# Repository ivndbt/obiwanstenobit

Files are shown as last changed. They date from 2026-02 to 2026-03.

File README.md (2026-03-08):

# ObiWanStenobit

Open-source steno keyboard with a pseudo-split layout, designed to be compact, portable, and cost-effective.

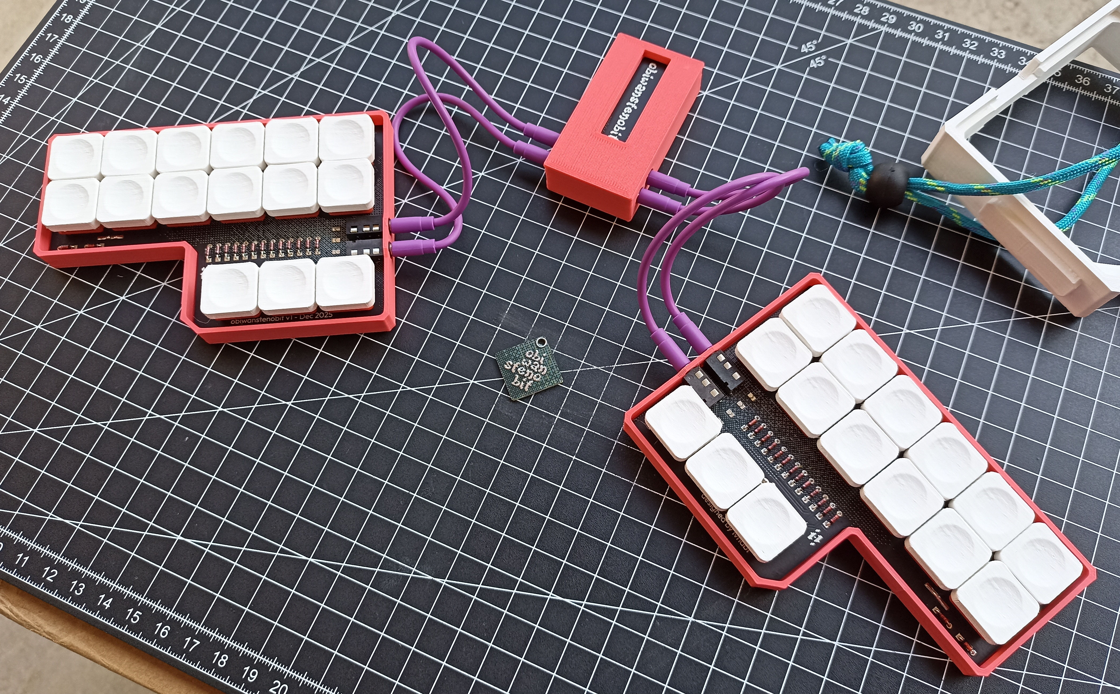
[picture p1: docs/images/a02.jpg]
ObiWanStenobit


## Overview

ObiWanStenobit (OWS) is a 30-key, steno-oriented mechanical keyboard designed with the primary goals of low manufacturing cost and ease of transport.

The keyboard uses a pseudo-split architecture: it is physically split into two halves, but relies on a single microcontroller rather than the dual-controller setup typical of traditional split keyboards.

The PCB is panelized and kept under 100x100mm to reduce fabrication costs and allow the keyboard to be built from a single PCB order (minimum 2 units).

The provided 3D-printable case is designed to be easily closed and to protect switches and electronic components during transport, making the keyboard suitable for backpack travel.

More information about the design process and development history are available at [ivndbt.com](https://ivndbt.com/makes/ows/ows.html)

## Features

- Pseudo-split steno layout
- Single microcontroller design
- Panelized PCB (< 100x100mm)
- Pro Micro compatible controller
- Kailh Choc v1 and v2 switch support
- Compact and travel-friendly form factor
- Open hardware design

## Repository structure

- `/`
  - Build guide (including BOM)
- `hardware/pcb/`
  - KiCad project files
  - Manufacturing-ready Gerber files
- `hardware/case/`
  - FreeCAD source files
  - STL files for 3D printing
- `docs/`
  - Images and additional files

## Hardware

### PCB

The PCB is designed in KiCad and provided both as source files and pre-generated Gerber files.  
Panelization is included in the design to minimize fabrication costs.

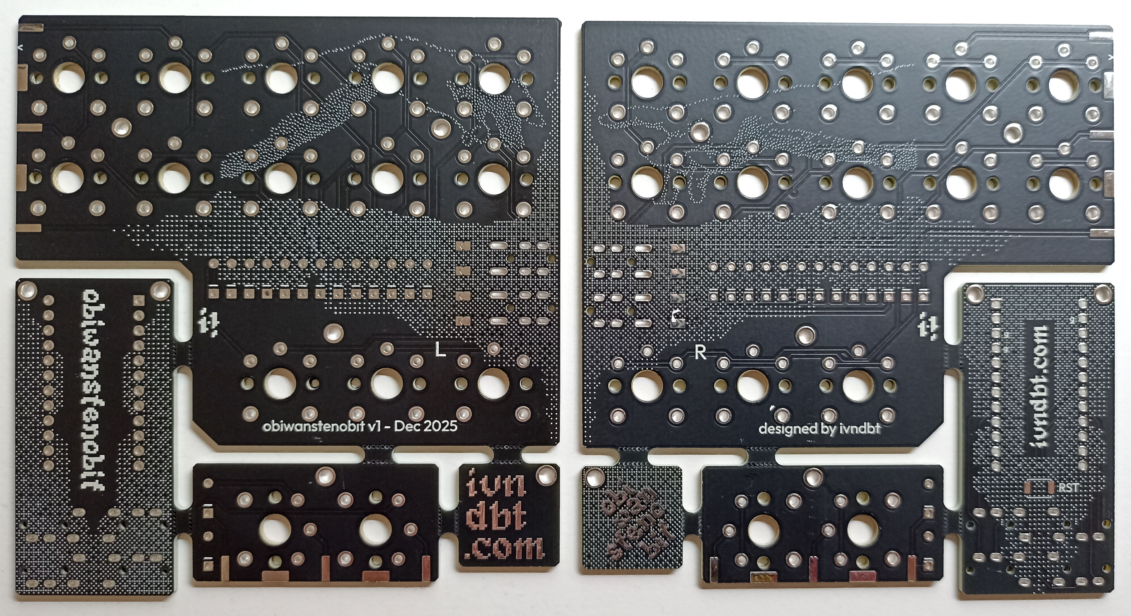
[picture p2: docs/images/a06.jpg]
PCB


### Case

The case is designed in FreeCAD.  
STL files provided in this repository should be considered the authoritative and up-to-date versions.
STLs hosted on [Printables]() are provided for convenience, but are not guaranteed to be updated to the latest revision.  

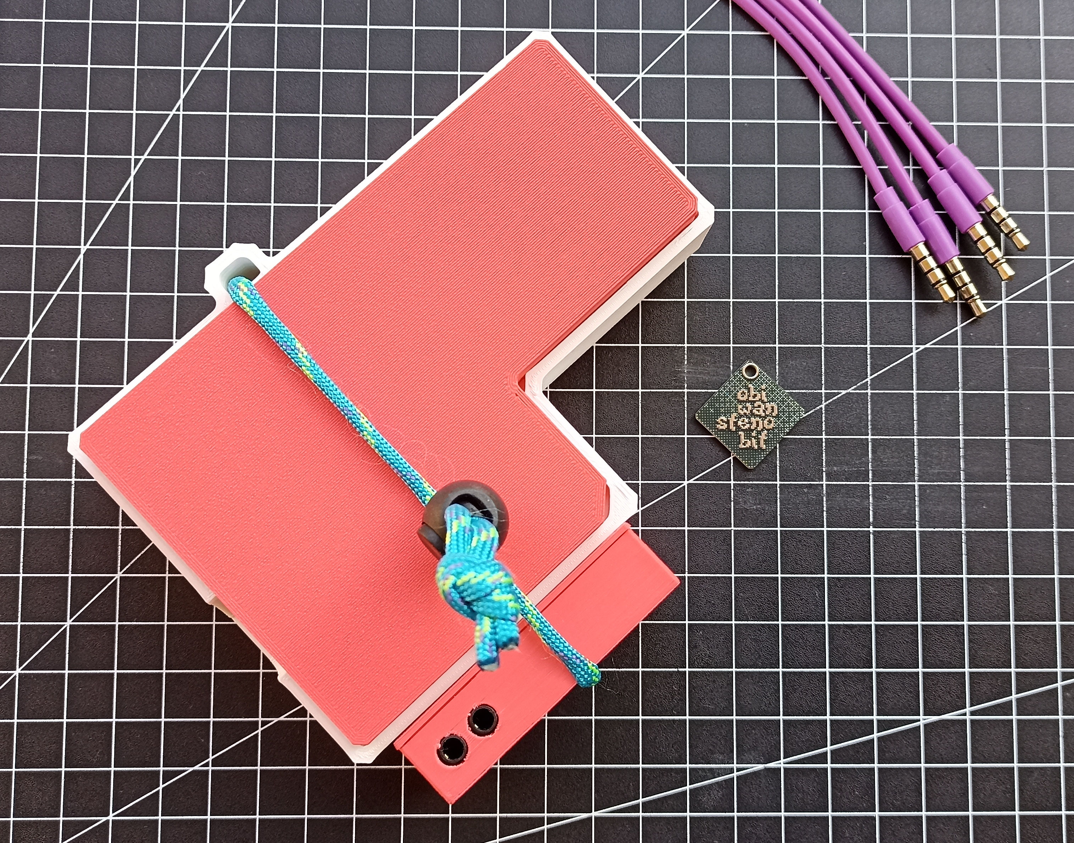
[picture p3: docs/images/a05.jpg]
Case


## Firmware

ObiWanStenobit can run on different firmware:

- QMK: [qmk/qmk_firmware](https://github.com/qmk/qmk_firmware/tree/master/keyboards/ivndbt/ows)
- ZMK: [ivndbt/zmk-config-obiwanstenobit](https://github.com/ivndbt/zmk-config-obiwanstenobit)
- Javelin: [ivndbt/javelin-steno-pico/artifacts_ows](https://github.com/ivndbt/javelin-steno-pico/tree/add-ows/artifacts_ows)
- VIA: [ivndbt/qmk_userspace](https://github.com/ivndbt/qmk_userspace/tree/add-ows-via) pending PR
- Vial: [vial-kb/vial-qmk](https://github.com/vial-kb/vial-qmk/tree/vial/keyboards/ivndbt/ows)

Firmware is maintained in the respective upstream repositories.

## Build guide

Assembly instructions and the complete Bill of Materials are provided in `build-guide.md`

## Extra files

`docs/` directory contains supplementary files related to the ObiWanStenobit keyboard development.

- `KLE-ows-via.json`: mapping matrix coordinates for [Keyboard Layout Editor](https://www.keyboard-layout-editor.com/).

## License

This project is licensed under **CERN Open Hardware Licence v2 (CERN-OHL-S)**.

You are free to use, modify, manufacture, and distribute this project under the terms of the license.
Any redistribution should include proper attribution and a reference to the original source:

    Based on ObiWanStenobit by ivndbt, licensed under CERN-OHL-S v2.
    Source: https://github.com/ivndbt/obiwanstenobit

See the `LICENSE` file for details.

If you are interested in producing this design, creating variants, or collaborating, you are welcome to get in touch via the email address found at [ivndbt.com](https://ivndbt.com/#contact).

## Sponsors

PCB prototyping was sponsored by [PCBWay](https://www.pcbway.com/), who kindly manufactured and provided the prototype boards.\
Fabrication quality and turnaround time were solid. Read more about it in [my blogpost](https://ivndbt.com/makes/ows/ows.html).

## References

- The ObiWanStenobit layout is inspired by [The Uni](https://stenokeyboards.com/products/the-uni-v4) from [StenoKeyboards](https://stenokeyboards.com/)
- The logo uses the [Kiwi Soda](https://fontenddev.com/fonts/kiwi-soda/) font from [fontenddev.com](https://fontenddev.com/)

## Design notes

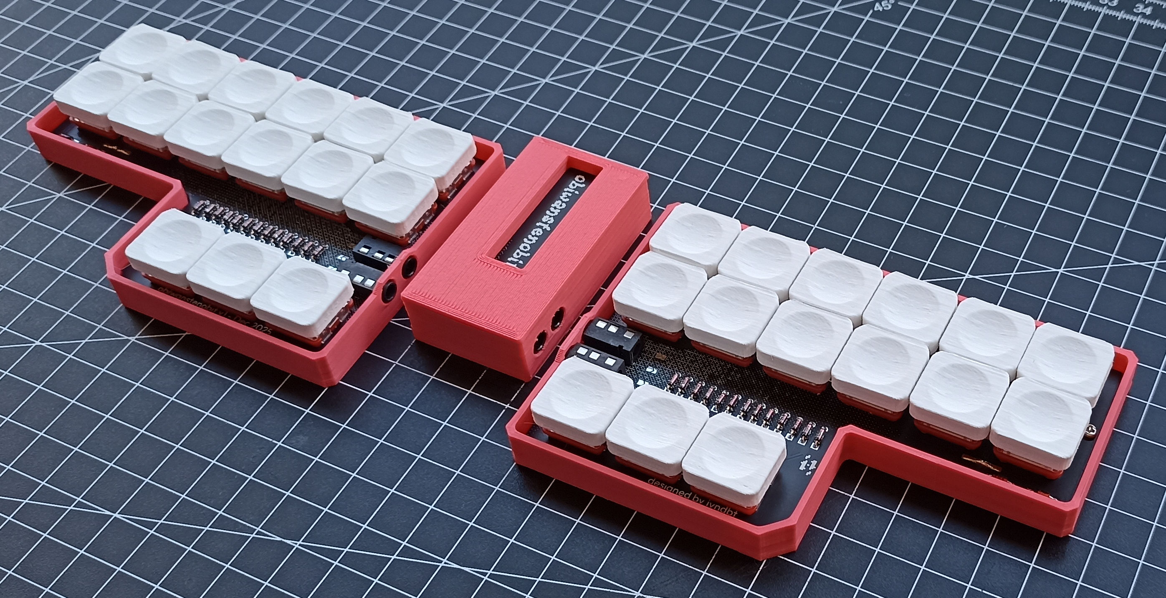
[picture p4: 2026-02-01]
docs/images/a01.jpg

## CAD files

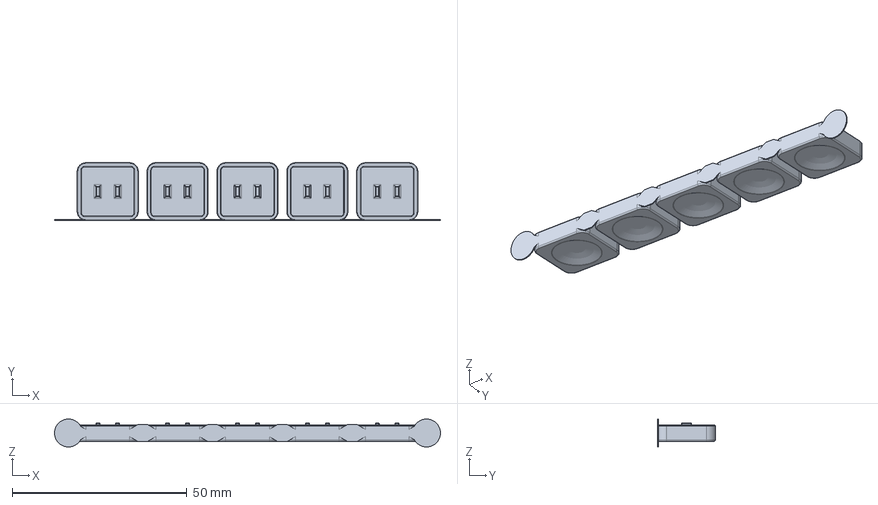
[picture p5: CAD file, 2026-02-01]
hardware/case/freecad/1c_choc_x5.FCStd
110.5 x 16.5 x 8.00 mm

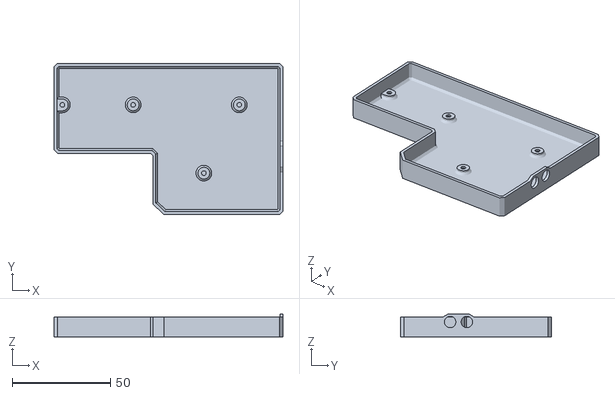
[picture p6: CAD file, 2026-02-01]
hardware/case/stl/kb-l.stl
116.5 x 77.0 x 11.6

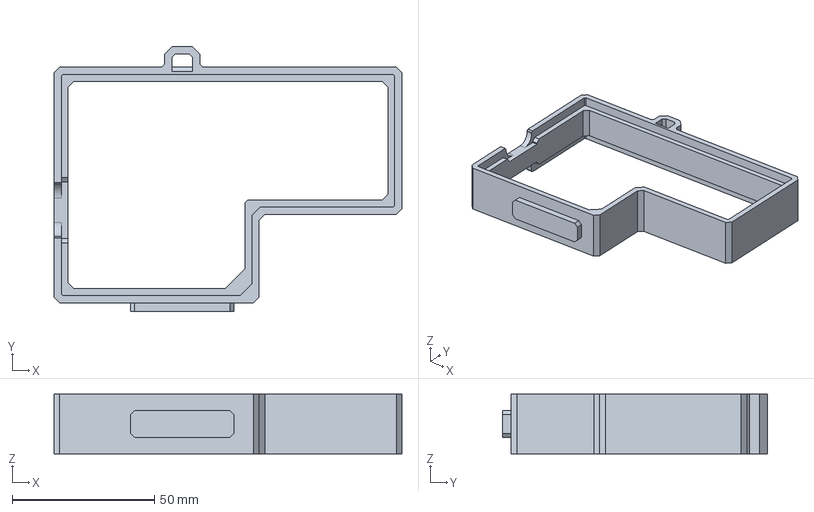
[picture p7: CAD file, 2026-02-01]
hardware/case/freecad/holder-v2.FCStd
122.5 x 93.2 x 21.0 mm

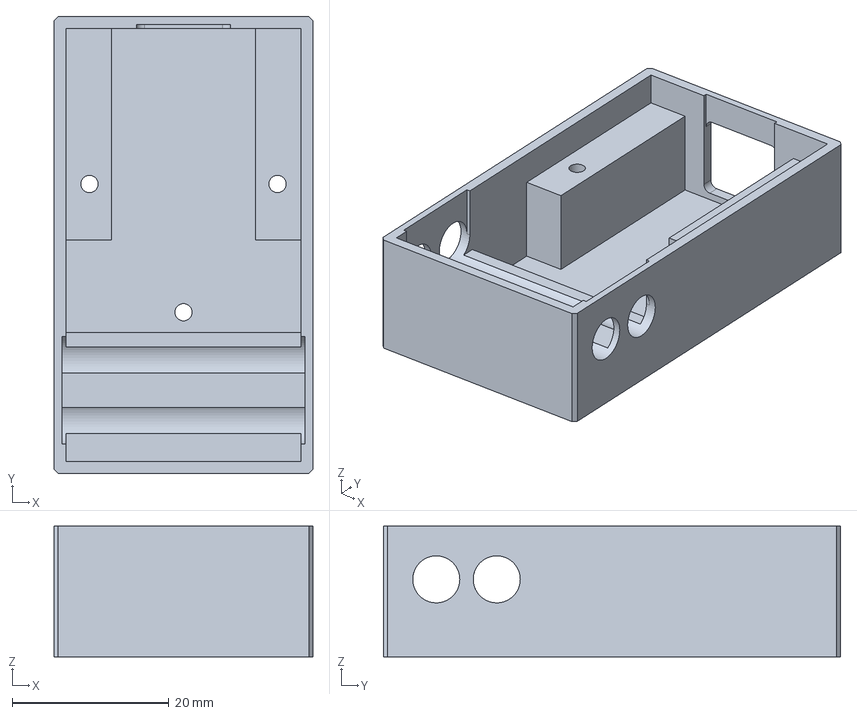
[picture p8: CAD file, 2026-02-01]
hardware/case/freecad/bay-bot-1.1.FCStd
33.0 x 58.3 x 16.7 mm

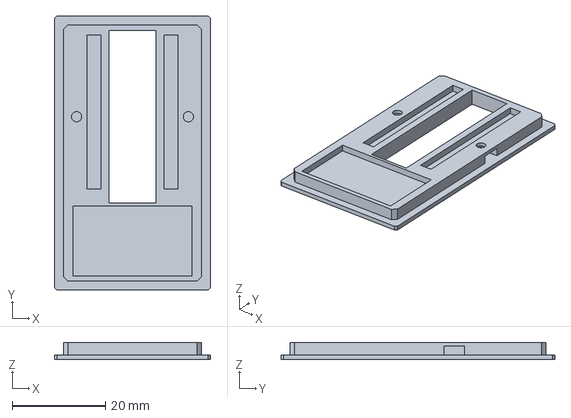
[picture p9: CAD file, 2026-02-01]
hardware/case/freecad/bay-top-1.1.FCStd
33.5 x 58.8 x 3.70 mm

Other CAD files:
hardware/case/freecad/kb-r.FCStd
hardware/case/stl/bay-bot-1.1.stl
hardware/case/stl/bay-top-1.1.stl
hardware/case/stl/holder-v2.stl
hardware/case/stl/kb-r.stl

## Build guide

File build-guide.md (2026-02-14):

# ObiWanStenobit – Build Guide

This document describes the complete build process for the **ObiWanStenobit (OWS)** keyboard, from PCB preparation to firmware flashing and initial steno setup.

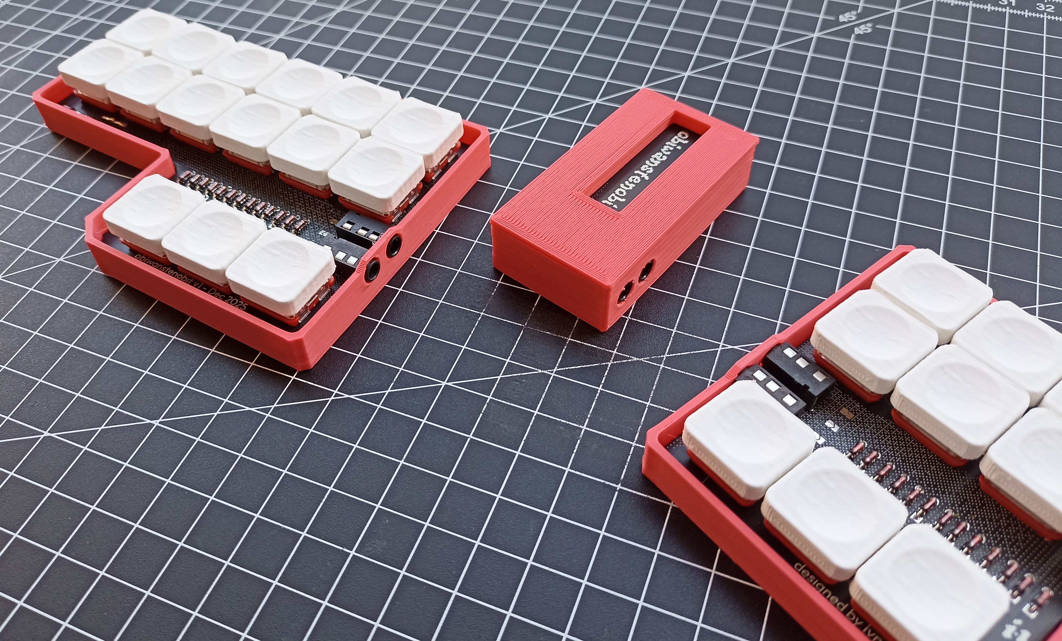
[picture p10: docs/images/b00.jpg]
Final result


## Bill of Materials

The following table lists all required and optional components needed to build a complete ObiWanStenobit keyboard compatible with the provided case.

| Ref. | Component | Description | Quantity | Links |
|---|---|---|---|---|
| 1 | PCBs | OWS panelized full set | 2 | [Gerbers](/hardware/pcb/gerber) |
| 2 | RP2040 | Pro Micro edition 16M | 1 | [Aliexpress](https://it.aliexpress.com/item/1005009348943760.html) |
| 3 | Socket | M2F 12-pin[^1] | 2 | [Aliexpress](https://it.aliexpress.com/item/1005007476809536.html) |
| 4 | Pins | MCU header pins[^1] | 24 | [Aliexpress](https://it.aliexpress.com/item/1005010342280815.html) |
| 5 | Kailh switches | Choc V1 (or V2) | 30 | [Aliexpress](https://it.aliexpress.com/item/1005008883418065.html) |
| 6 | PJ-320A | THT TRRS jack socket[^2] | 8 | [Aliexpress](https://it.aliexpress.com/item/1005007334594658.html) |
| 7 | Tactile switch | SMD 2-pin 4x3x2mm | 1 | [Aliexpress](https://it.aliexpress.com/item/1005010586092874.html) |
| 8 | Diode | DO-35 1N4148 | 30 | [Aliexpress](https://it.aliexpress.com/item/32947233235.html) |
| 9 | TRRS cables | Male-to-male TRRS cable[^2] | 4 | [Aliexpress](https://it.aliexpress.com/item/32462922130.html) |
| 10 | Pins | M2M header pin | 6 | [Aliexpress](https://it.aliexpress.com/item/4000988113226.html) |
| 11 | Keycaps | Compatibles with Choc V1 | 30 | [STL](/hardware/case/stl) / [Aliexpress](https://it.aliexpress.com/item/1005009100305250.html) |
| 12 | Case | | 1 | [STL](/hardware/case/stl) |
| 13 | Screws | M2x4mm cylindrical head PH  | 8 | [Aliexpress](https://it.aliexpress.com/item/32971605141.html) |
| 14 | Screws | M2x10mm cylindrical head PH | 2 | [Aliexpress](https://it.aliexpress.com/item/32971605141.html) |
| 15 | Nuts | M2 hex | 10 | [Aliexpress](https://it.aliexpress.com/item/1005007796257329.html) |
| opt. | Rubber feet | | 8 | [Aliexpress](https://it.aliexpress.com/item/1005002619943801.html) |
| opt. | Nut | 1/4in-20 | 1 | |
| opt. | Paracord | 550 | 50cm | [Aliexpress](https://it.aliexpress.com/item/4000176073490.html) |
| opt. | Spring buckle | | 1 | [Aliexpress](https://it.aliexpress.com/item/1005003036732343.html) |

[^1]: To socket the MCU as low as possible, the use of Mill-Max pin headers is recommended.

[^2]: TRRS connectors (4 rings) are required.

## Required and Recommended Tools

### Required tools

- Soldering iron
- Solder wire
- Flush cutters
- Pliers
- Tweezers
- Fine-grit sandpaper

### Recommended tools

- Flux

## Terminology and PCB Nomenclature

The following terminology is used throughout this guide:

- **Main Keyboard PCB**: the primary PCB hosting the majority of switches (left and right)
- **2-Key Expansion PCB**: the auxiliary PCB hosting the additional two keys
- **Controller PCB**: the PCB hosting the microcontroller and connectors

## PCB Preparation

Separate all PCBs by breaking the mouse bites from two full PCB sets.  
One extra Controller PCB will remain unused.

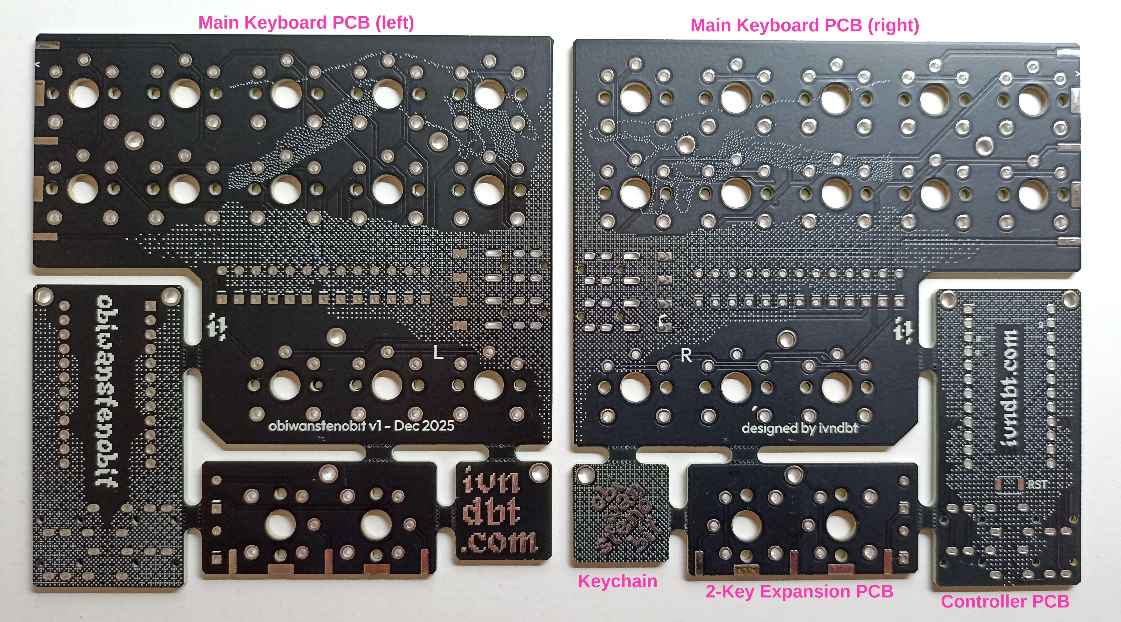
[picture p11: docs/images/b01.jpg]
2 full sets of PCBs


Place a sheet of fine-grit sandpaper on a flat surface and gently sand the PCB edges to remove mouse bite remnants.  
Edges should be smooth to the touch.

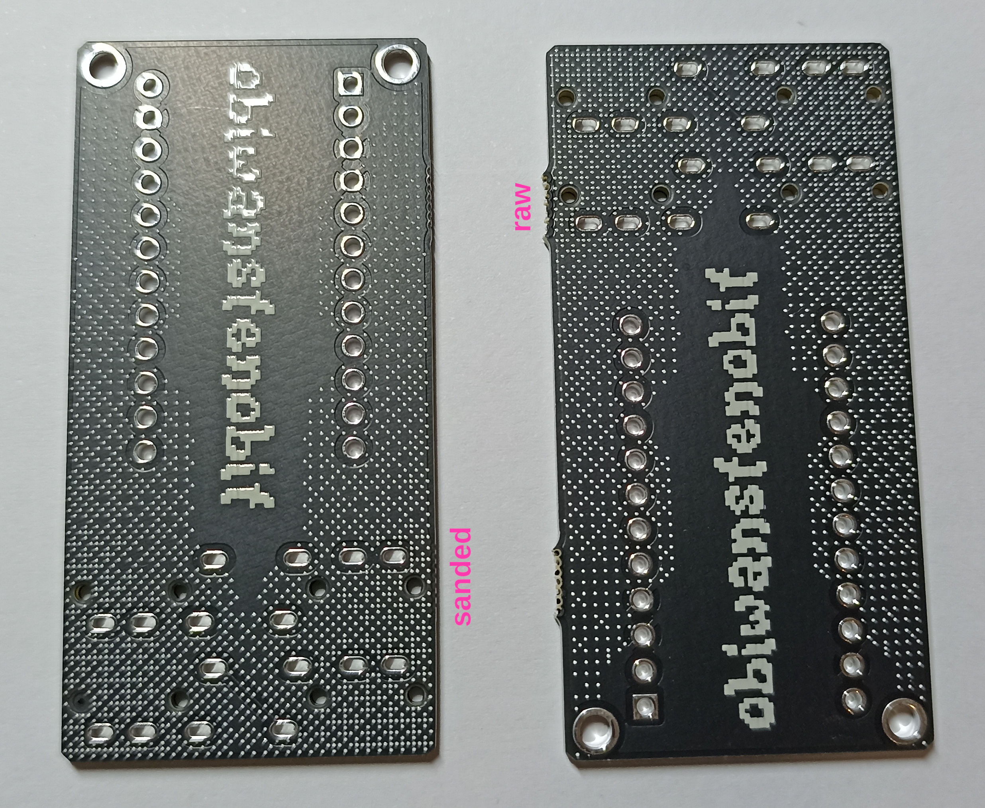
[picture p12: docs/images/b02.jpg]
Before and after edge sanding


## Controller Preparation

This section is based on the guide provided for the Aurora series by [splitkb.com](https://splitkb.com/).  
Refer to the [original documentation](https://docs.splitkb.com/product-guides/aurora-series/build-guide/microcontrollers#using-mill-max-pins) for additional images.

Using sockets allows the microcontroller to be removed or replaced if necessary.  

Before starting, identify the correct controller orientation.  
The MCU is mounted above the **ivndbt.com** logo, with the chip facing the user.

Insert the sockets into the controller PCB and solder **one pin per socket** first.  
Check alignment carefully: if needed, reheat the joint and adjust.  
Once aligned, solder the remaining outer pins.

Before inserting the header pins, place a thin **plastic barrier** over the sockets to prevent solder from flowing inside them.  
Kapton tape is recommended, but a piece of sturdy plastic is fine too.
Failing to do this step can permanently solder the controller to the sockets, making removal nearly impossible.

Insert the header pins into the sockets one by one, pushing them fully.  

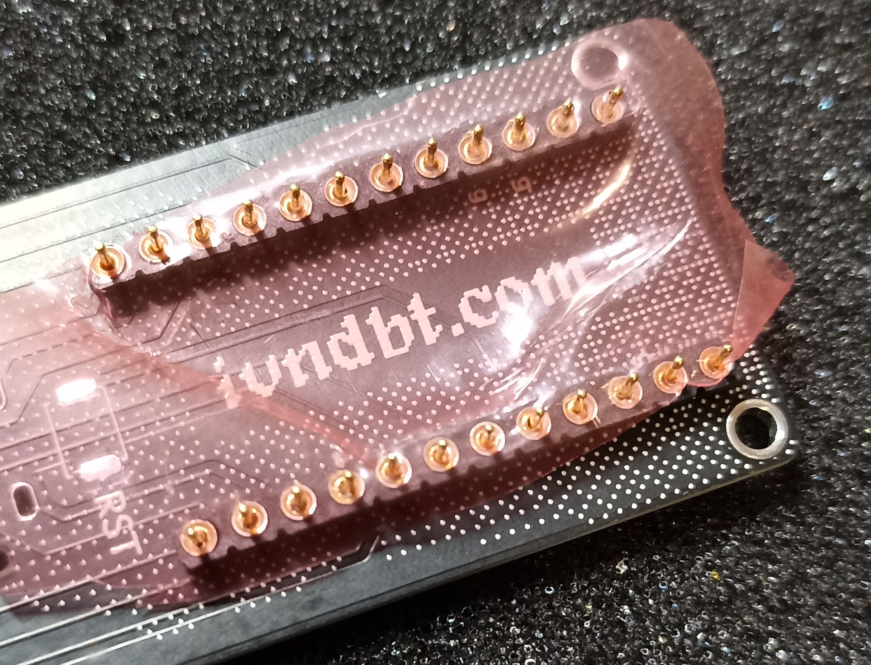
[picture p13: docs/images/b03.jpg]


Place the microcontroller onto the pins and solder it in place.

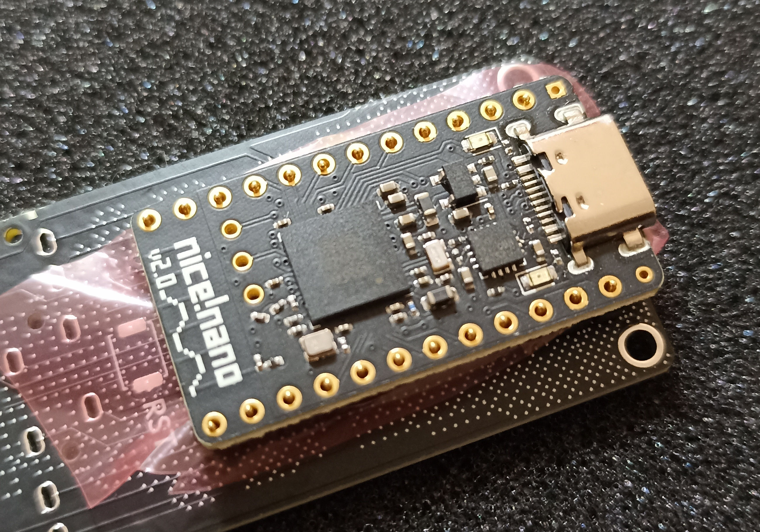
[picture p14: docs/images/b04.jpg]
nice!nano position


The image shows a nice!nano controller, but the procedure is identical for the RP2040. If your pins are too long, cut them with the flush cutter.

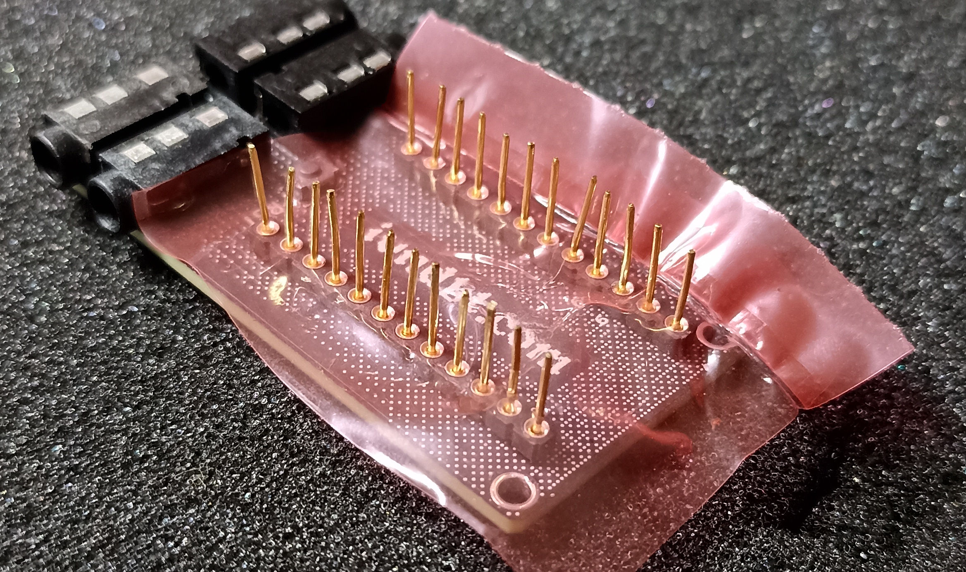
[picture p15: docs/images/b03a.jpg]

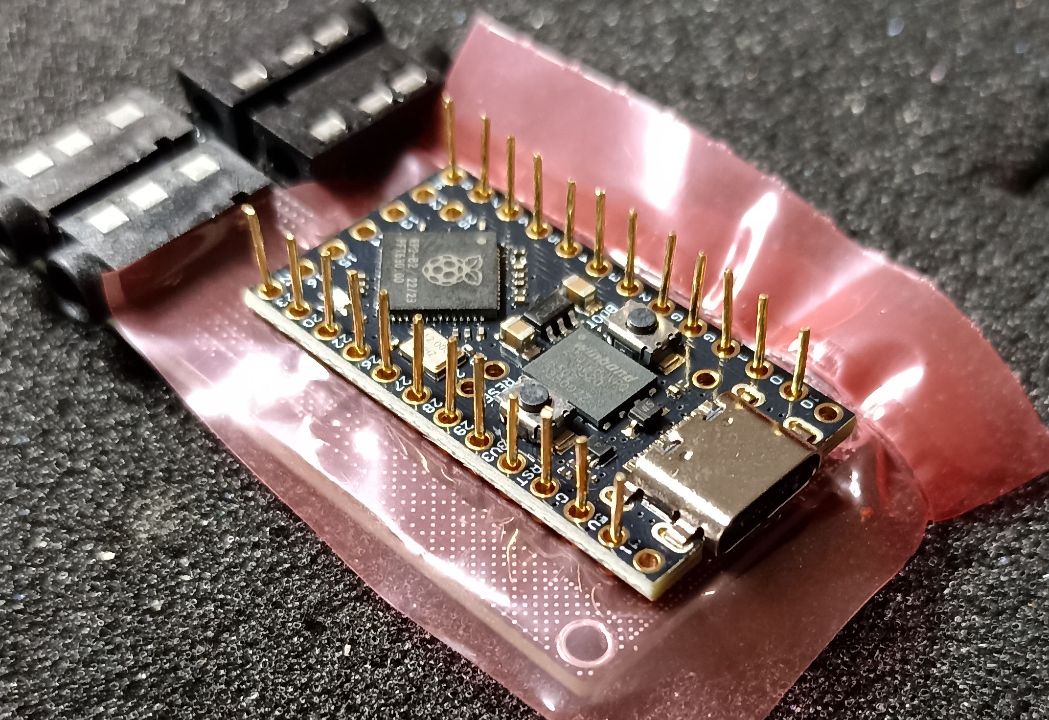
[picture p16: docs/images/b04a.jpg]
RP2040 position

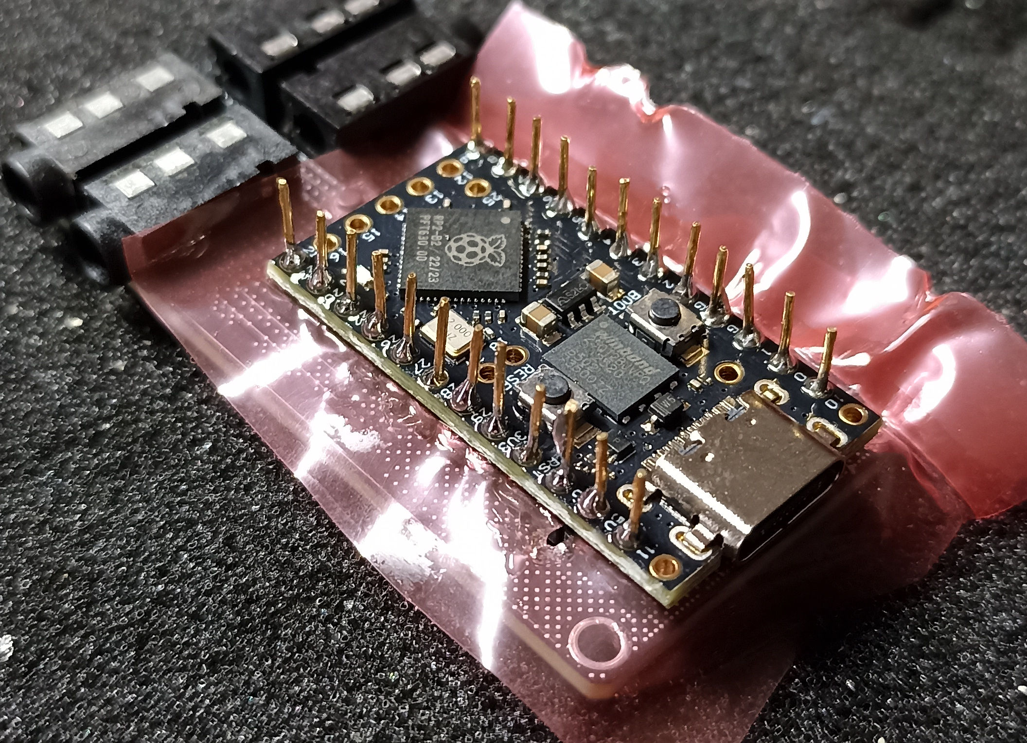
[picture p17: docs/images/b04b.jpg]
RP2040 soldered with long pins

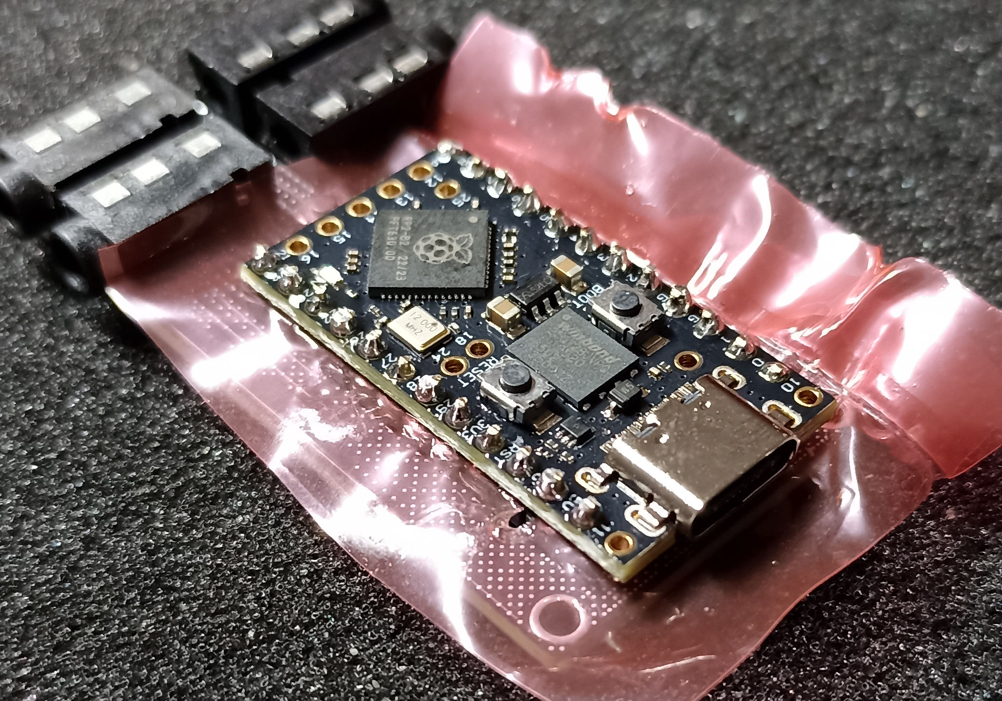
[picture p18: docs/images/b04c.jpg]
RP2040 pins cut


>The two holes near the USB connector must not be soldered in both cases.

After soldering, carefully remove the plastic layer.  
Take care not to bend the controller pins when mounting or removing the MCU.

## Controller PCB

Complete the controller PCB by soldering:

- The reset button
- The four TRRS jack sockets

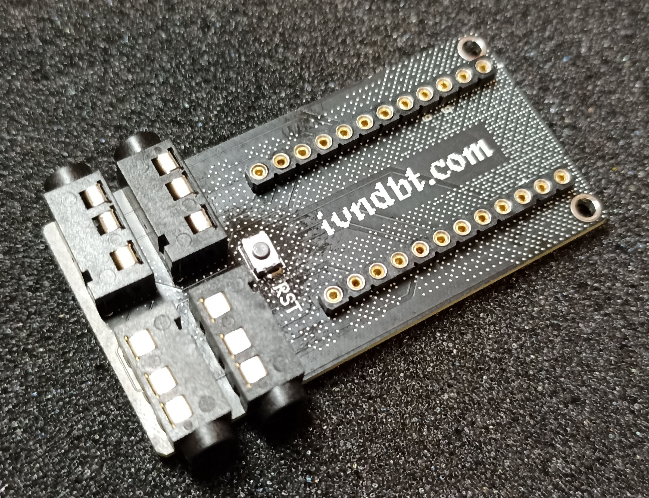
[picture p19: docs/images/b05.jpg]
Complete Controller PCB


## Main Keyboard

### Soldering the PCBs

Place the Main Keyboard PCB and the 2-Key Expansion PCB on a flat surface with the switch side facing up.  
Align the edges carefully and solder the interconnecting pads generously.

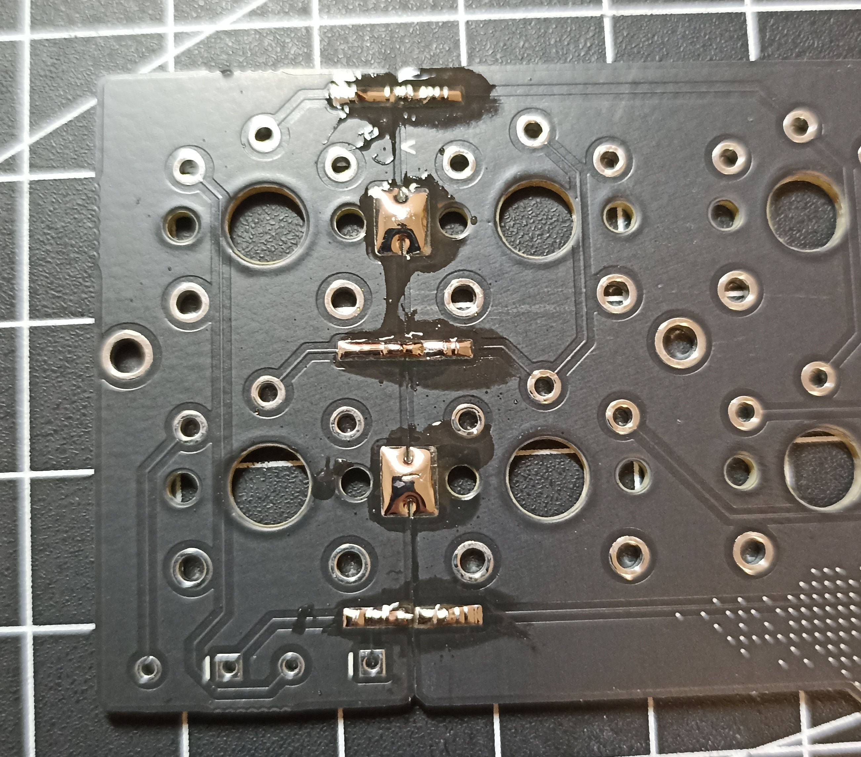
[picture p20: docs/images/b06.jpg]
Frontside connection


Flip the PCB assembly and solder the pads on the backside as well.

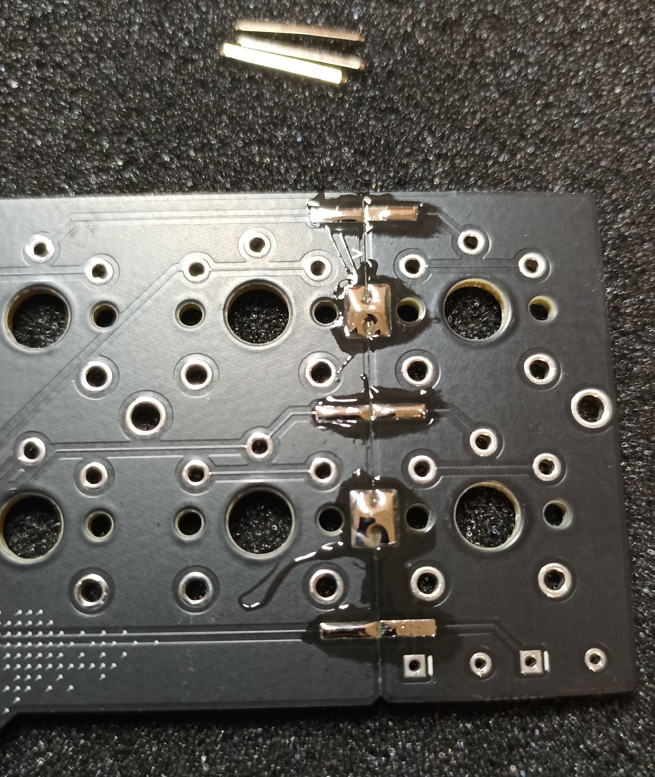
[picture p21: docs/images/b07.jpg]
Backside connection


For improved mechanical strength, it is recommended to embed a square-section header pin into each of the thin interconnection pads **on the backside**.
To do this, reheat the solder and gently place the pin into position. Add solder if necessary to secure it.

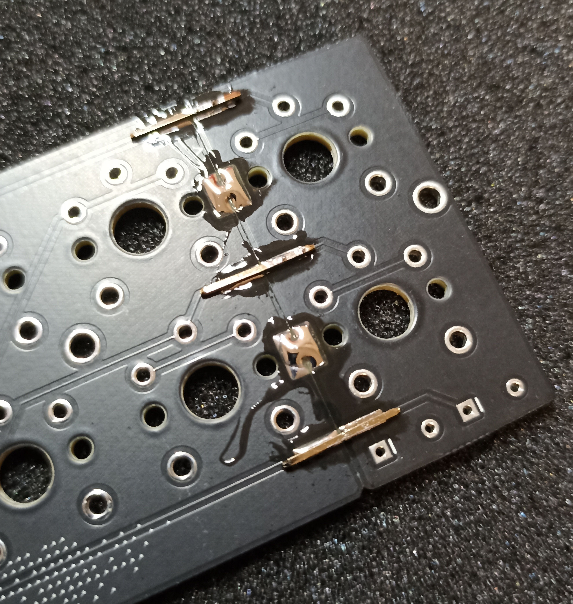
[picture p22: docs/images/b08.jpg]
Backside reinforced connection


### Diodes

Identify diode polarity.  
The line printed on the PCB marks the cathode and must align with the line on the diode.

Bend the diode leads as close as possible to the diode body before insertion.  

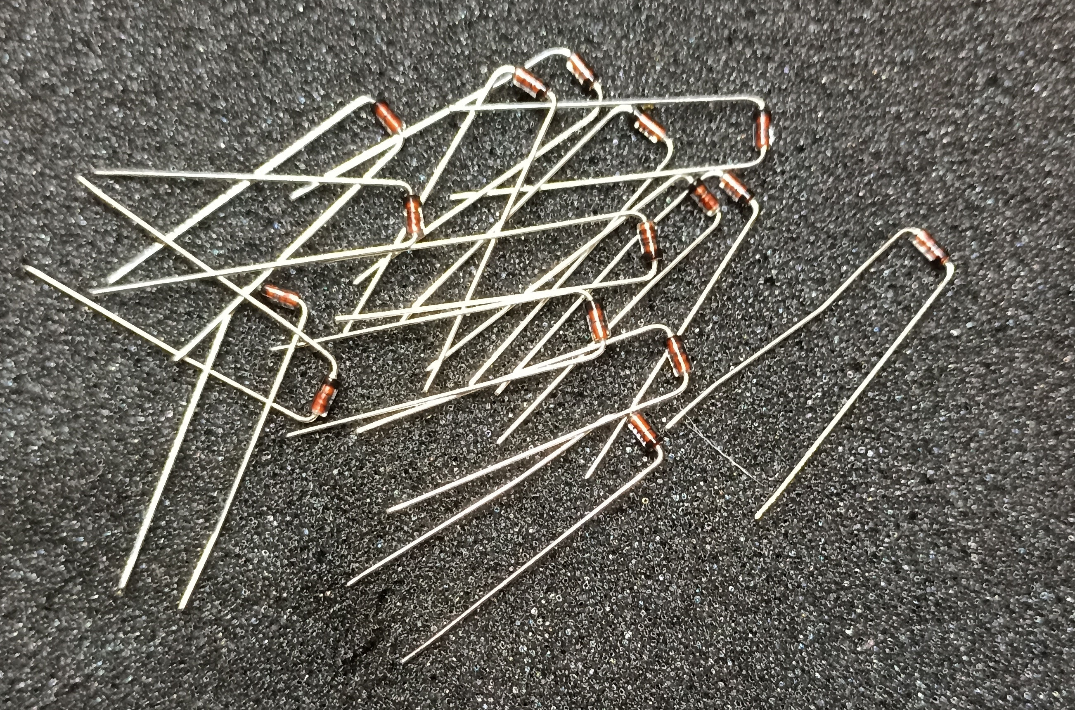
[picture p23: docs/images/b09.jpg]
Diodes preparation


Solder all diodes on the front side of the PCBs and cut the exceeding leads.

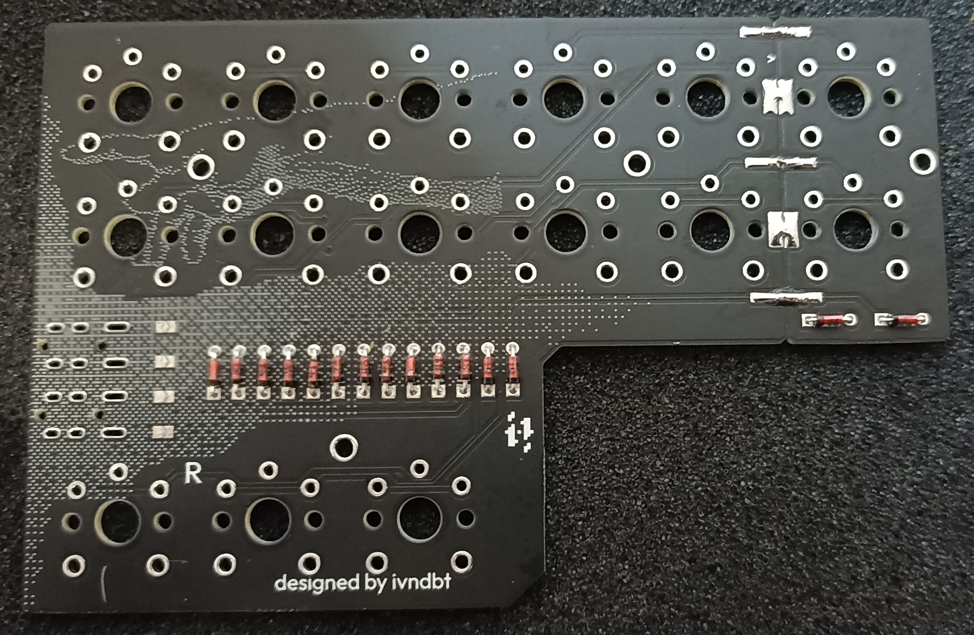
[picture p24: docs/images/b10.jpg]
Diodes soldered


### Jack Sockets and Solder Jumpers

On the front side of the PCBs, place and solder all jack sockets.

Solder **only the solder jumpers on the backside of both PCBs**.  
The solder jumpers on the front side **must not** be soldered.

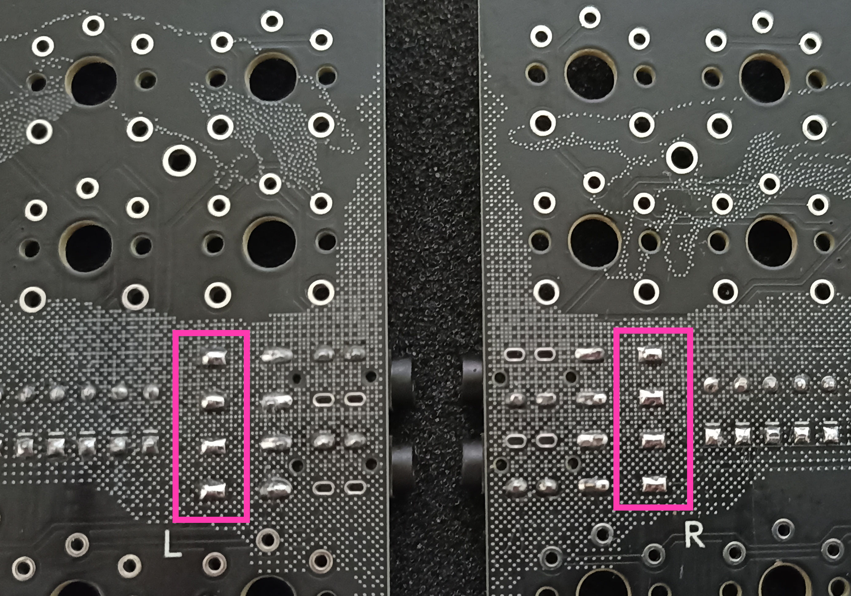
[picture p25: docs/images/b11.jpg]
Backside closeup of the PCB solder jumpers


### Keyswitches

Insert Kailh Choc switches into the PCB.

- Choc V2 switches will click into place
- Choc V1 switches will sit loosely until soldered

Solder all switch pins.

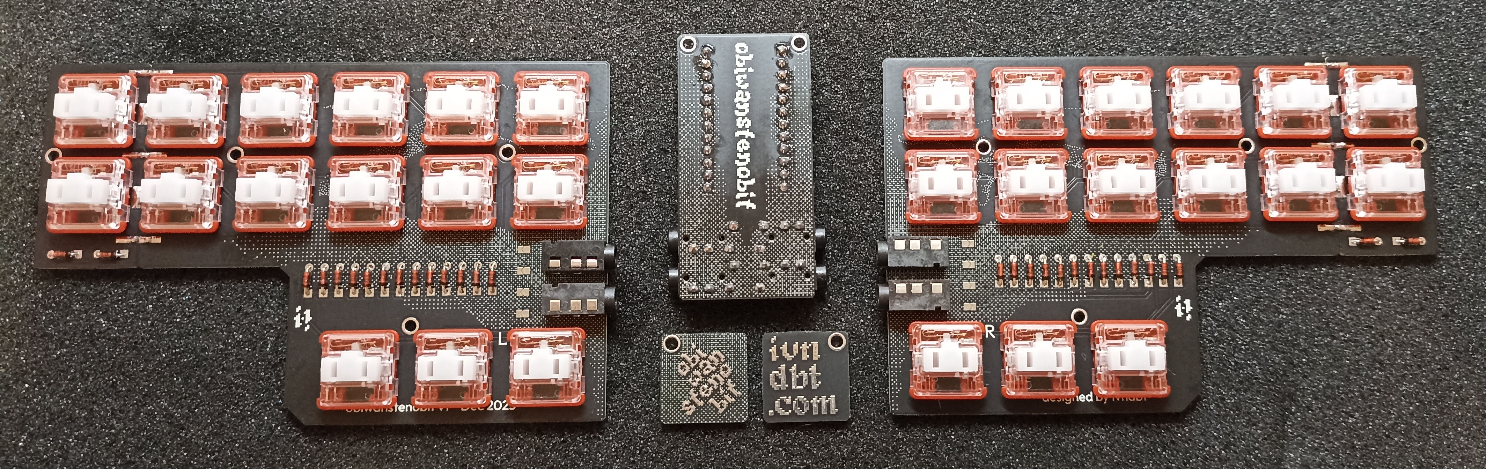
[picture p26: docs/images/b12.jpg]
Solder work finished


## Firmware Flashing

Prepare the firmware of your choice and flash it to the microcontroller following the instructions on the respective repositories. The supported firware are listed on the [main readme](/README.md#firmware).

### Testing

Connect each keyboard half to the Controller PCB.  
The ObiWanStenobit logo should face the user, and the USB connector should face away, as shown in the reference image.

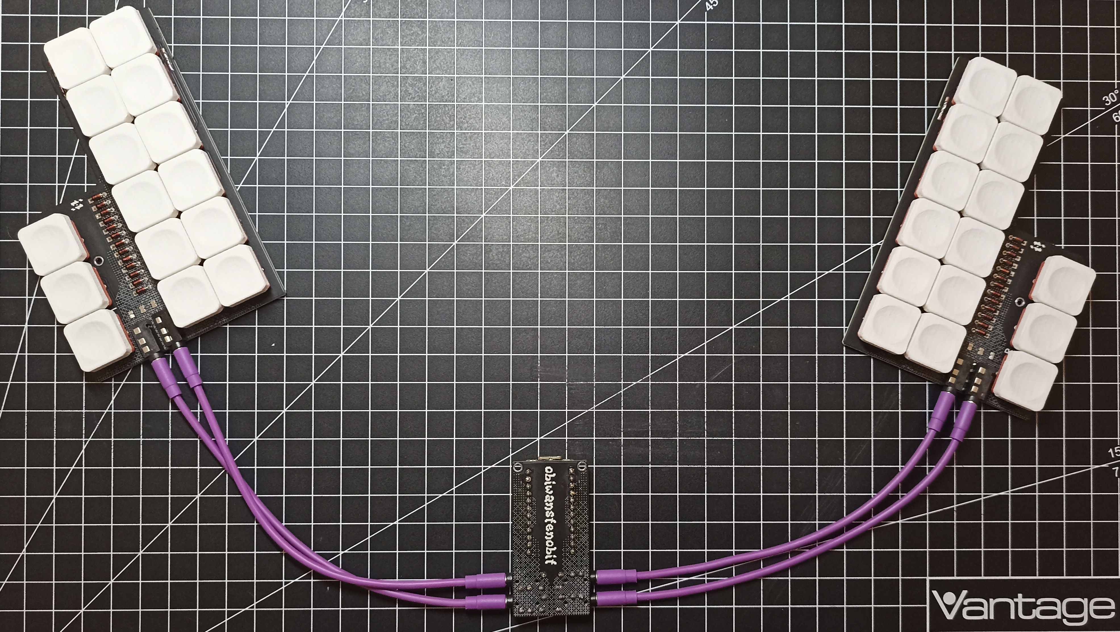
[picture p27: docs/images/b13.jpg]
Connecting PCBS


Test the key matrix and verify correct left and right side behavior.

## Keycaps and Case

Print the case, holder, and keycaps using the provided [STL files](/hardware/case/stl).  
Sand edges if necessary.

> When printing the Main Keyboard PCB case, insert a G-code pause just before the nut cage ceiling is printed.  
> Place the four nuts in position and resume printing.

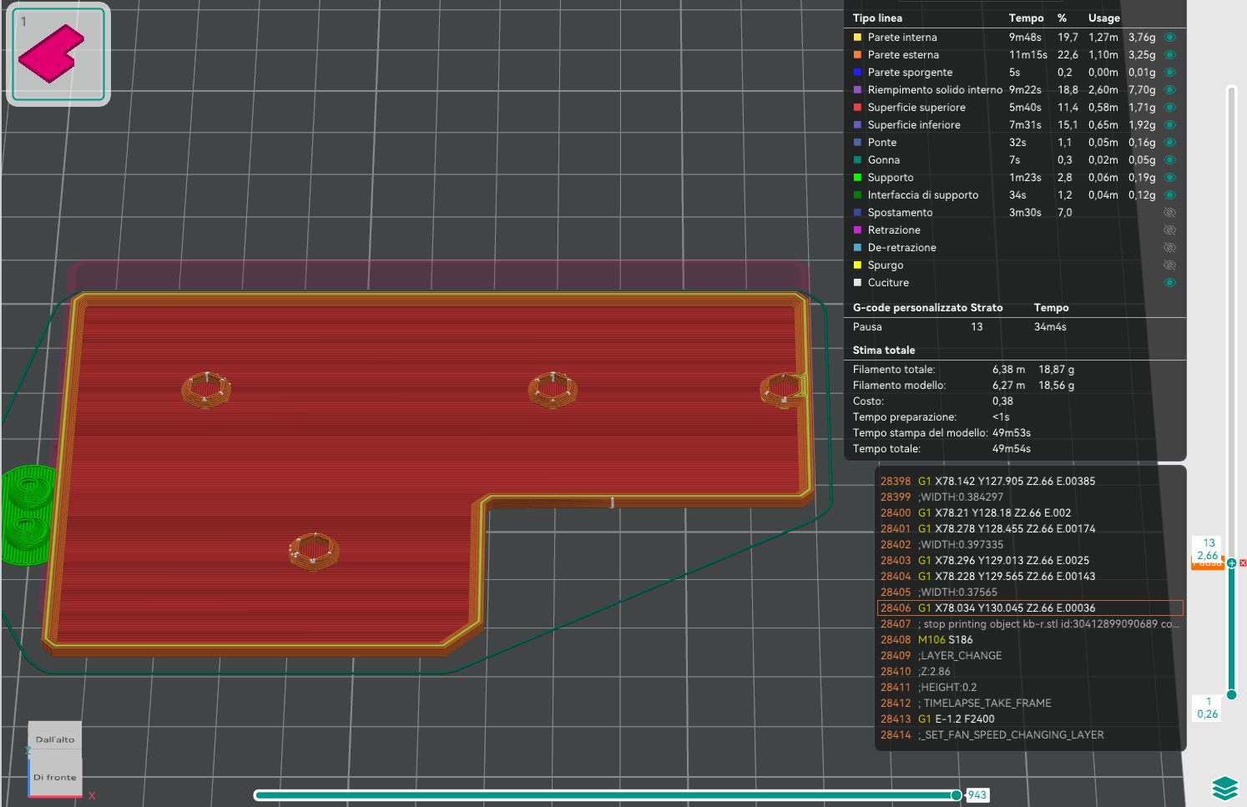
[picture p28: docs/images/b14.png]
Slicer pause

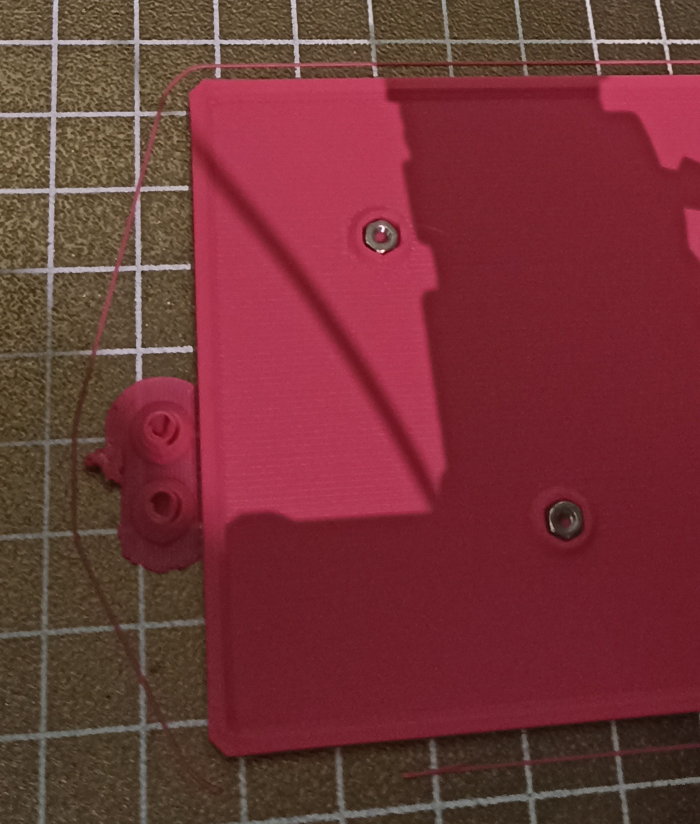
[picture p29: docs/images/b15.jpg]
Nuts positioning


Assemble the printed case components and install the PCB assembly using:

- M2x4mm screws to fix Main PCBs to their case (8 screws in total)
- M2x10mm screws to make the Controller PCB bay

Place the keycaps.

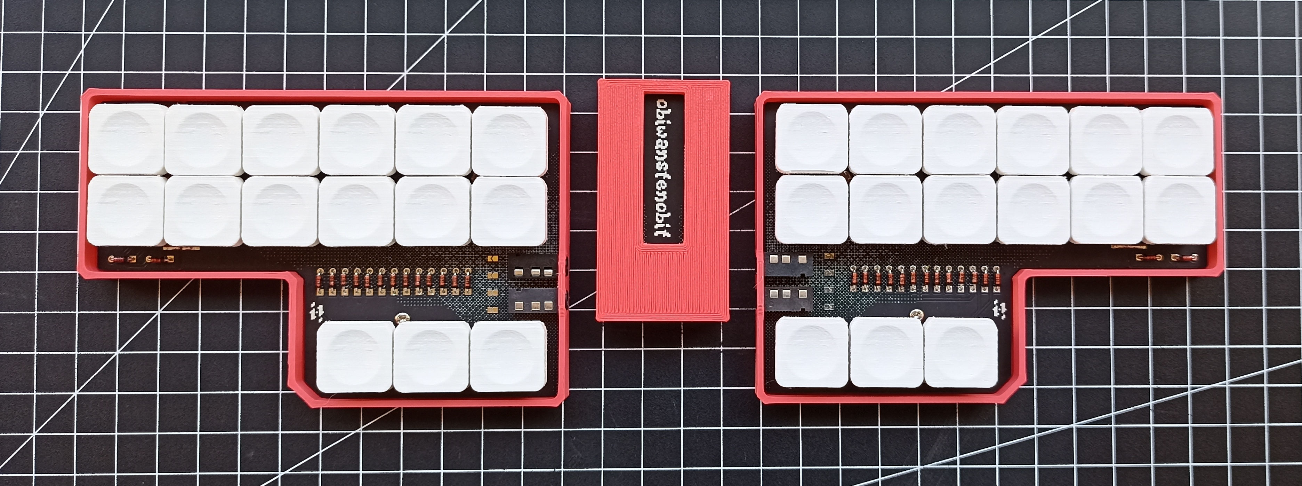
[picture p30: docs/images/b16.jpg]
Keyboard completed


Optional:
- Apply rubber feet to the bottom of the case for stability
- For an ergonomic angle, glue a 1/4in-20 nut to the bottom of the case and mount it on a tripod or similar support

### Holder Assembly

Pass the paracord through the holder hole and install the spring buckle.  
Secure it with a knot and melt the cord ends to prevent fraying.

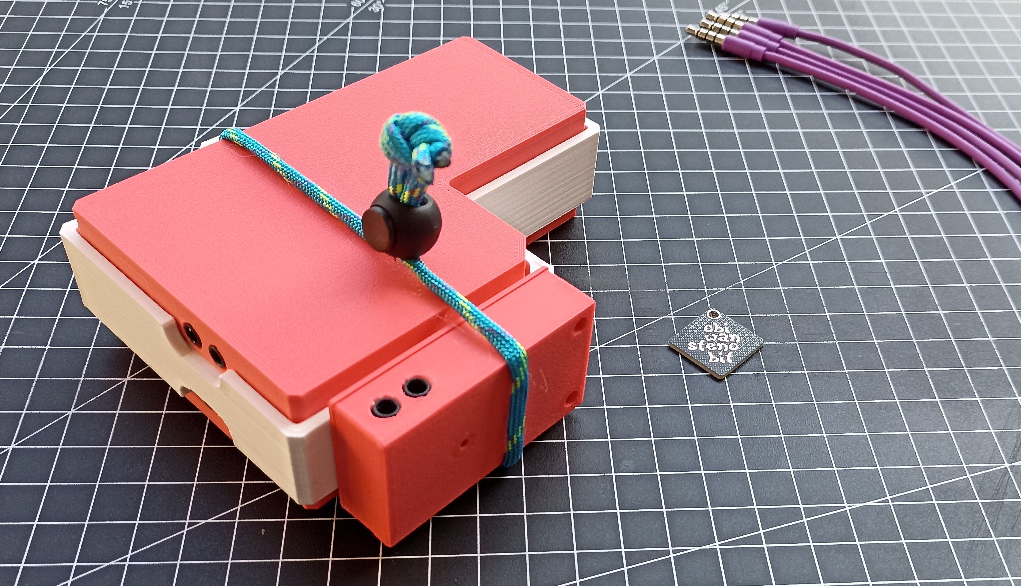
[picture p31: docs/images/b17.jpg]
Holder in use


## Plover Setup

Install Plover following the [official documentation](https://plover.wiki/index.php/Plover_software).

Configure the keyboard:

- When using QMK, select the **GeminiPR** protocol
- When using ZMK, select the **Keyboard** protocol and configure key bindings accordingly

Learning and practice resources:
- https://plover.wiki/index.php/Category:Learning_stenography
- https://didoesdigital.com/typey-type/

## Extras

When using a Bluetooth-capable controller (e.g. nice!nano), the keyboard can be made wireless by soldering a LiPo battery to the pads labeled **B+** and **B-** near the USB connector.

The recommended battery model is **301230**.  
Refer to the [official documentation](https://nicekeyboards.com/docs/nice-nano/) for details. 

> Note: This modification enables wireless communication between the MCU and the host device, but the four TRRS cables between the main PCBs and the controller PCB are still required.

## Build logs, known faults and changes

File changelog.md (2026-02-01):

# Changelog

All notable changes to this project are tracked in this file.

## [1.1] - 2026.01.27

### Changed

- Updated the controller case dimensions
- Repositioned the controller PCB mounting holes to improve alignment with the case
- Updated the controller PCB by slightly increasing its width

### Fixed

- Fixed missing silkscreen elements on the 2-Key Expansion PCB

## [1.0] - 2025.12.27

### Added

- Initial prototype of the ObiWanStenobit keyboard (not publicly released)

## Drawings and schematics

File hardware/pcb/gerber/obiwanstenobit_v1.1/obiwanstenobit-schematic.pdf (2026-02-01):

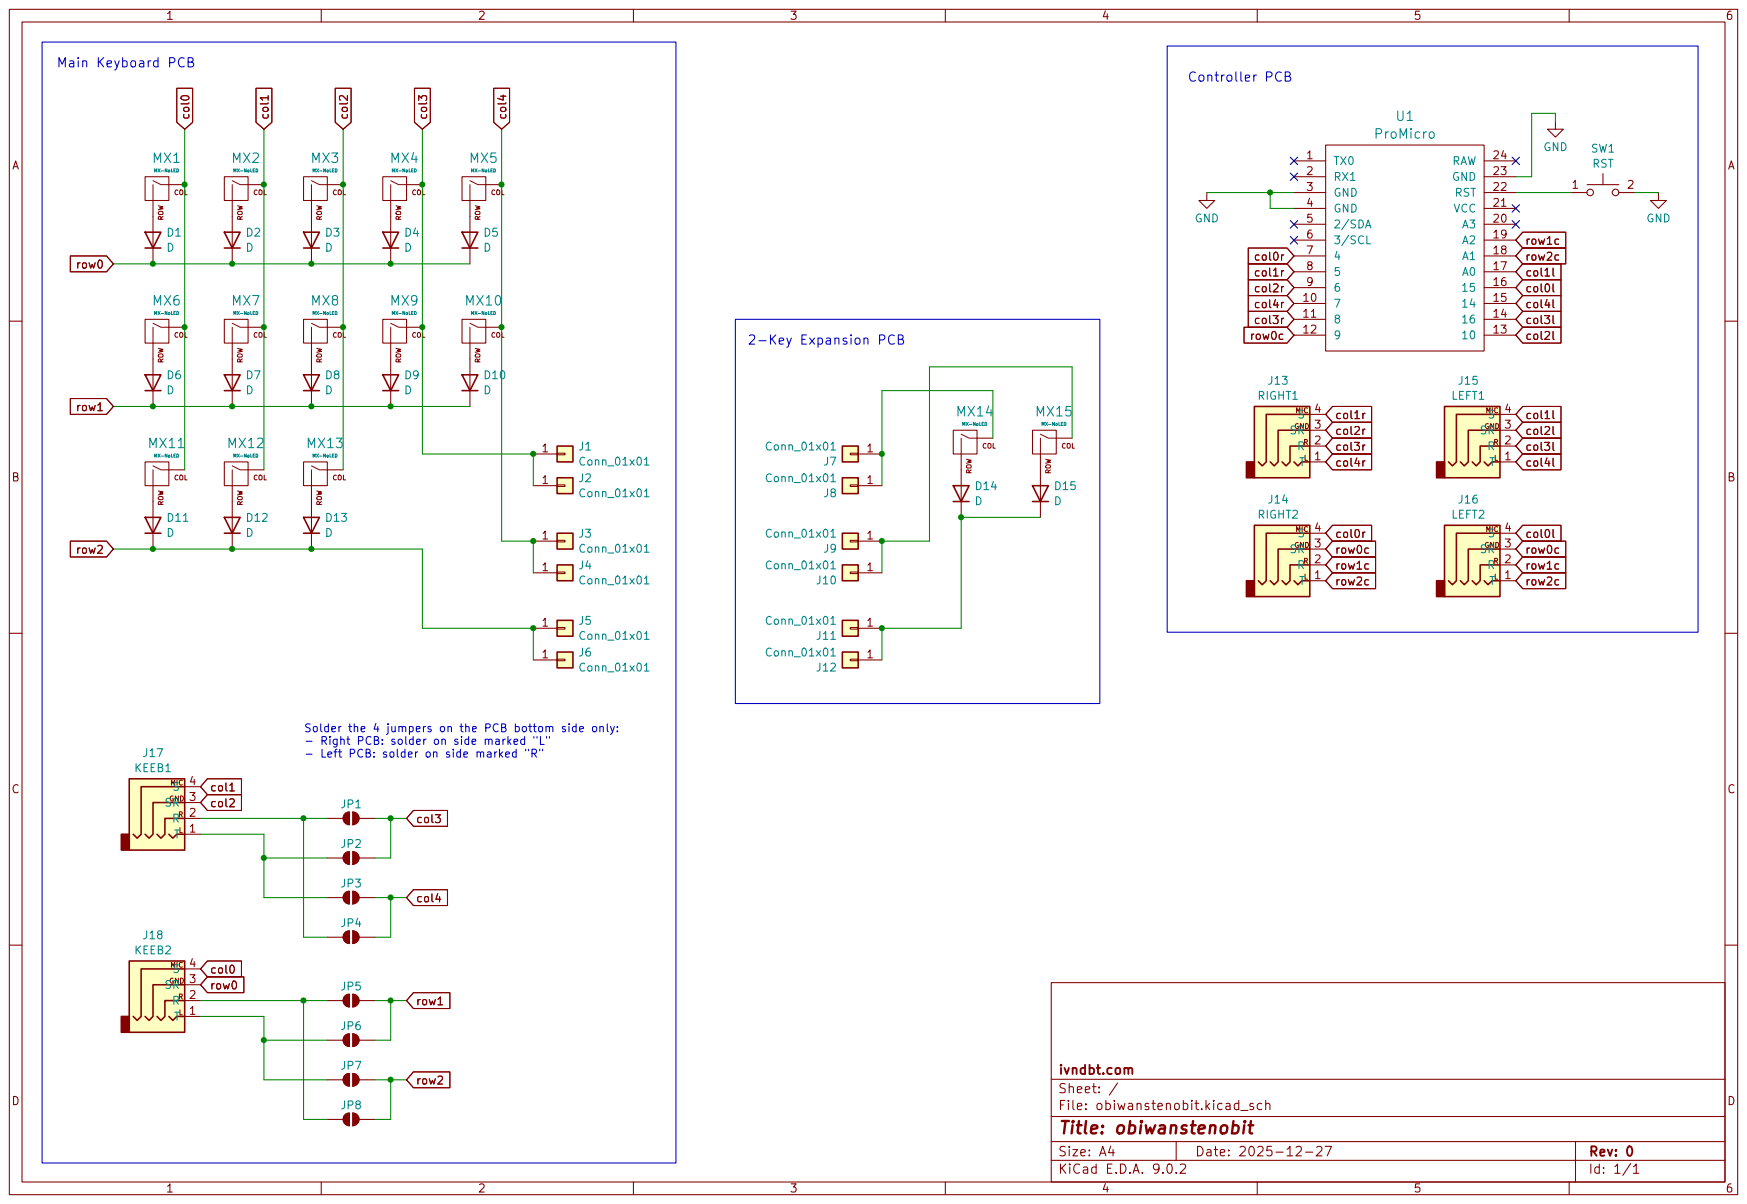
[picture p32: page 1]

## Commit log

2026-02-01 released version 1.1
    [bay-bot-1.1.FCStd, bay-bot-1.1.stl, bay-top-1.1.FCStd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]
2026-02-01 added keycaps 3d files
    [1c_choc_x5.FCStd]
